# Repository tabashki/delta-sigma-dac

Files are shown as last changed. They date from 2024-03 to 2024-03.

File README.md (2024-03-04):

Delta-Sigma DAC
===============

This repo contains the OrCAD 17.4 schematic and board layout files for a prototype digital-to-analog converter project I created for a *Computer Design of Electronic Circuits* elective course I took at the [Faculty of Physics at Sofia University](https://www.phys.uni-sofia.bg/).

3D visualization of the manufacturing artwork files *(left)* and photo of the first production prototype *(right)*. Manufactured by [JLCPCB](https://jlcpcb.com/).

<p float="left">
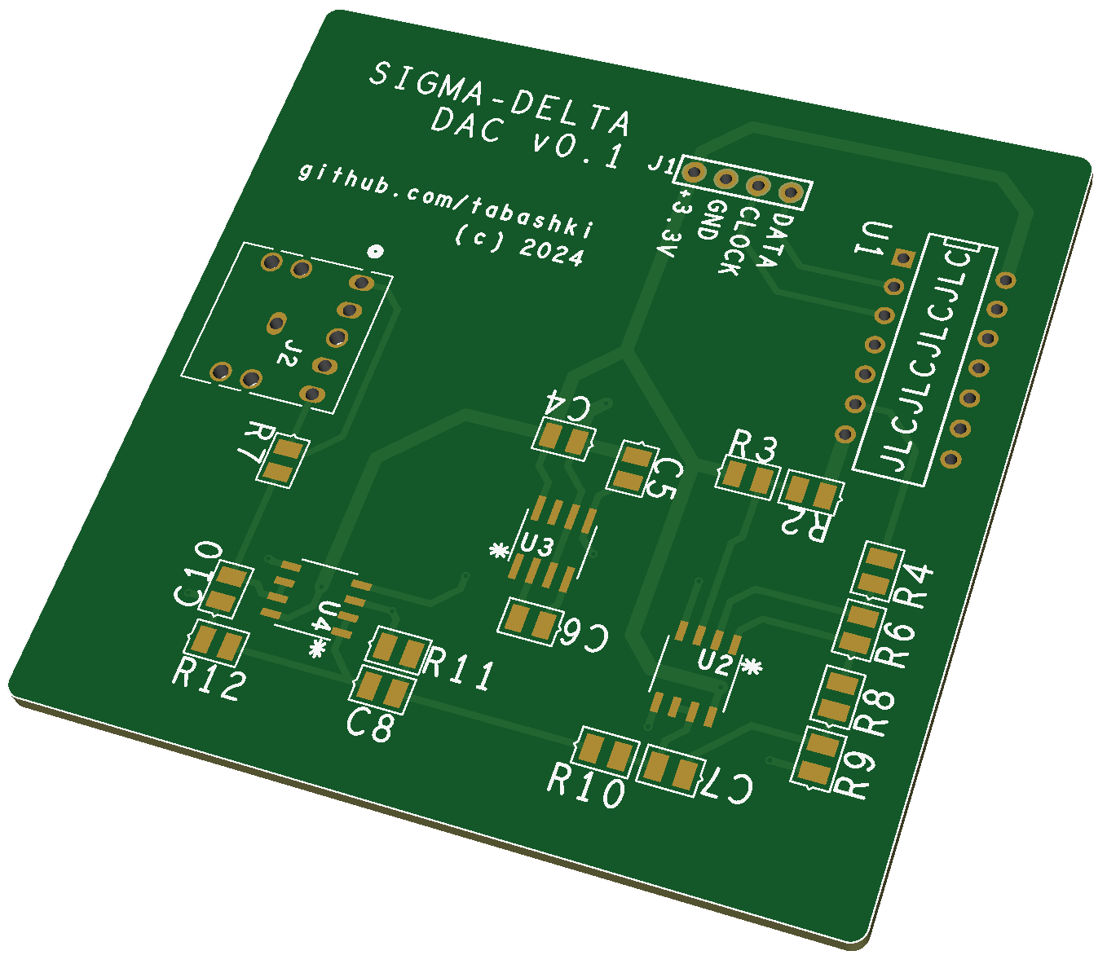
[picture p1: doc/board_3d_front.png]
    
    
</p>

Design Goal
===========

The goal of the project was to construct a rudimentary DAC from discrete digital and analog components that could reasonably function at clocks rates of at least 500 kHz.

The board is powered by a 3.3V DC input and is expected to output a standard -500mV to +500mV line-level signal. The expected input is a 3.3V [pulse-density modulated](https://en.wikipedia.org/wiki/Pulse-density_modulation) digital signal. The signal is latched and demodulated using a 1-bit DAC and a 3-stage, 6th order Butterworth Sallen-Key low-pass filter, the output of which is sent to the 3.5 mm jack output.

Documentation
=============

Signal Path
-----------
The following is a simplified diagram of the signal path:

```mermaid
graph TD;
    in["Clock/Data In"] --> lat["D Latch"];
    lat["D Latch"] --> dac["1-bit DAC (Op-amp)"];
    dac["1-bit DAC (Op-amp)"] --> lpf["Low-Pass Filter Stages 1-3"];
    lpf["Low-Pass Filter Stages 1-3"] --> jack["Jack Output"];
```

Schematic
---------

The full PDF schematic of the cicuit can be found [here](/doc/schematic.pdf).

Bill of Materials
-----------------

An Excel BOM sheet with corresponding links to the Bulgarian parts distrubutor [Comet Electronics](hhttps://www.comet.bg/) can be found [here](/doc/bill_of_materials.xlsx)

Other
-----

A PDF writeup for the coursework in Bulgarian can be found [here](/doc/documentation_bg.pdf).

The PDF slides for the final presentation that was given in front of the class in Bulgarian can be found [here](/doc/presentation_bg.pdf).

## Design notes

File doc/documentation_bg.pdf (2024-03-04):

## Софийски Университет „Св. Климент Охридски“

### Физически Факултет

# П Р О Е К Т

## на тема

## Изработване на прототипна платка за ΔΣ цифрово-

## аналогов преобразувател (ЦАП)

## курс

## Компютърно Проектиране на Електронни Схеми

Изготвил: | Иван Руменов Табашки
Ф. №: | 6PH0900015
Проверил: | доц. д-р Станимир Колев

## Съдържание

## 1. Увод и цел

Делта-сигма модулаторите са схеми за преобразуване на аналогови сигнали в

редица високочестотни цифрови импулси. С допълнителна цифрова филтрация може

този изходен сигнал да се превърне в еквивалентен дискретизиран по време и квантуван

по амплитуда сигнал. Както при други видове аналогово-цифрови преобразуватели,

важно е да имаме нискочестотен пред-филтър след аналоговия вход за да се избегнат

ефектите от aliasing. Но за разлика от другите ЦАП схеми, при делта-сигма

модулаторите се налага в порядък по-висока честота на дискретизация от максималната

на входния сигнал [1]. По този начин може да реконструираме сигнала до bit-depth или

sampling-rate, какъвто желаем като се използва още по-висока тактова честота.

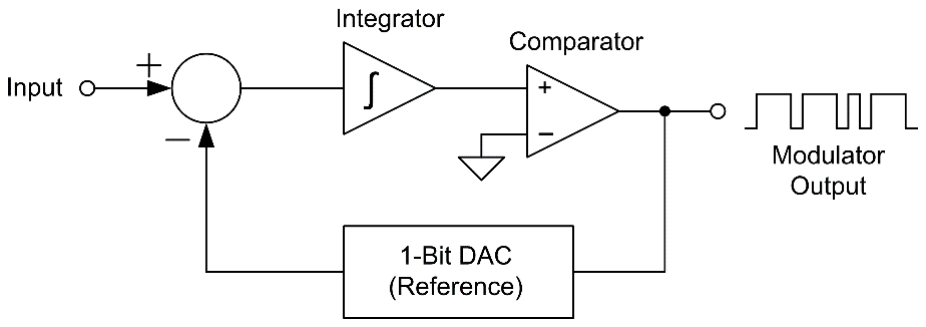
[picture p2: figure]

Фигура 1. Блок-схема на прост делта-сигма модулатор [2]

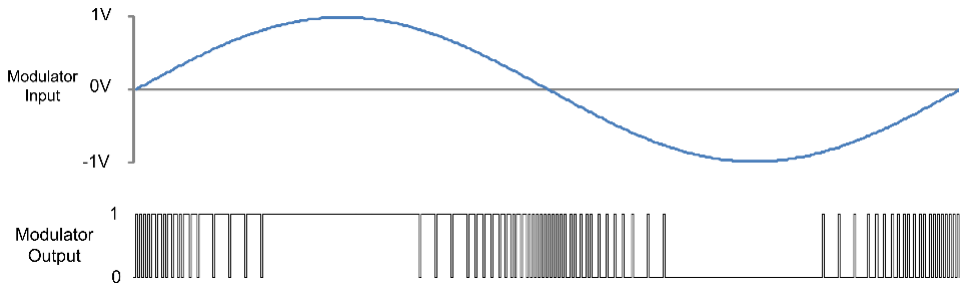
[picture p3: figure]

Фигура 2. Примерен изходен сигнал на модулатора [2]

Делта-сигма демодулаторите съответно извършват обратната операция, на

изхода им се получава нискочестотен аналогов сигнал на базата на високочестотния

цифров pulse-density модулиран сигнал на техния вход. Това позволява те да вършат

работа на цифрово-аналогови преобразуватели, като може да се наложи цифрова

обработка на сигнала, ако той е квантуван с висок bit-depth.

В този проект ще се разглежда създаването точно на такъв делта-сигма ЦАП,

който да служи за генериране на стандартен, line level звуков сигнал [3], така че да може

с усилвател той да бъде възпроизведен на високоговорител.

## 2. Описание на схемата

Схемата се състои от 4 основни блока - генератор на отрицателно -3.3V отправно

напрежение, входен D-тригер, който управлява еднобитов ЦАП, осъществен чрез

операционен усилвател, изхода на който минава през активен Sallen-Key Butterworth

нискочестотен филтър. Схемата е предвидена да бъде захранвана с постоянно 3.3V

напрежение от външен източник. Отрицателното -3.3V напрежение се генерира с

помощта на charge-pump DC-to-DC интегрална схема TC7660.

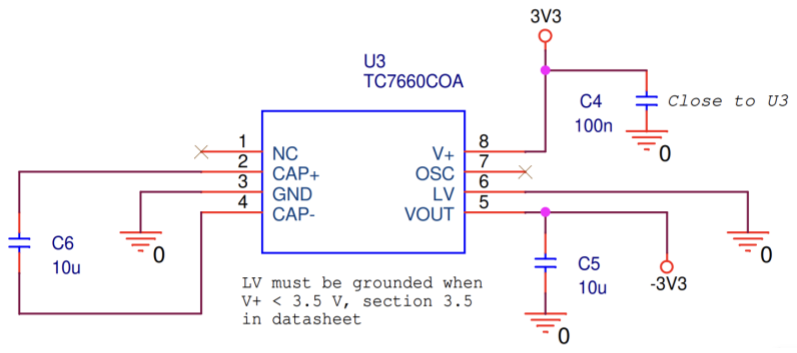
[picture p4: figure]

Фигура 3. Схемата на генератора на -3.3V, конфигурацията е взета от TC7660 datasheet

D-тригера е интегрална схема SN74HC74N, на която D и CLK входовете са външни

за цялата схема и са изведени на входния конектор, и се очаква да се управляват от външен микроконтролер Raspberry Pi Pico [4], а Q̅ изхода е свързан към отрицателния

вход на операционен усилвател с +3.3V и -3.3V захранване. Отрицателната обратна

връзка на операционния усилвател е подбрана, така че коефициента му на усилване да е

приблизително 0.303, а чрез резисторен делител се добавя постоянно положително

отместване приблизително 0.5V. Целта на това е да превърне цифровия изход със CMOS

нива (0 ÷ 3.3V) към -0.5V ÷ 0.5V нивата очаквани за стандартен line-level изход [3].

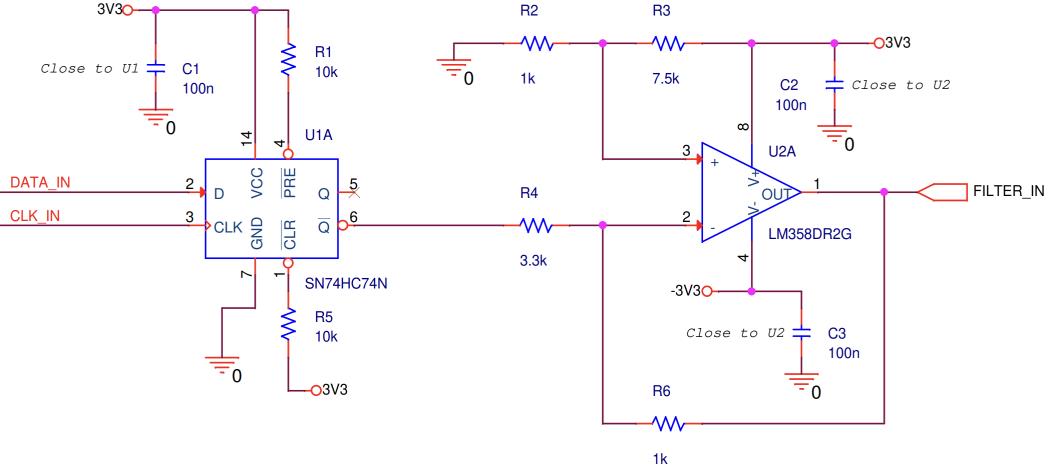
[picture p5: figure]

Фигура 4. Схемата преди нискочестотния филтър

След професионална консултация, в схемата са добавени 100 nF кондензатори на

захранванията на всяка интегрална схема, това е с цел да се избегнат смущения по

захранващите релси и земи. В схемата тези кондензатори са отбелязани с допълнителни

отметки “Close to Ux” за да е ясно по време на дизайн на платката, че те трябва да са във

физическа близост до дадената интегрална схема.

Най-сложната част от цялата схема е финалния нискочестотен филтър, на който

параметрите съществено влияят върху качествата на цялата схема като ЦАП. За целта е

избран да е Butterworth филтър, поради добрата му линейност и липса на сериозни

изкривявания на сигнала близо до cutoff честотата.

Интегралната схема LM358 съдържа двойка операционни усилватели, така че като

за начало имаме един свободен операционен усилвател, който може да използваме за

изграждането на филтър тип Sallen-Key. Проблема, е че така най-много да можем

Butterworth филтър от втори ред да конструираме. По тази причина с добавката на още

една интегрална схема LM358, ще имаме общо 3 операционни усилвателя на

разположение, с които може да създаден Butterworth филтър от 6-ти ред, който има доста

по-добра стръмност след cutoff честотата му.

Тъй като сметките за стойностите на филтър с толкова стъпала вече не е тривиално,

за целта се използва онлайн калкулатора на Uwe Beis [5], който може да сметне филтър

до 10-ти ред, както и да наглася стойностите на компонентите да са от стандартните

поредици. За малко подсигуряване поради вариации в компонентите, филтъра е

пресметнат да е с cutoff честота 16 kHz, резултатните стойности са записани във фиг. 5.

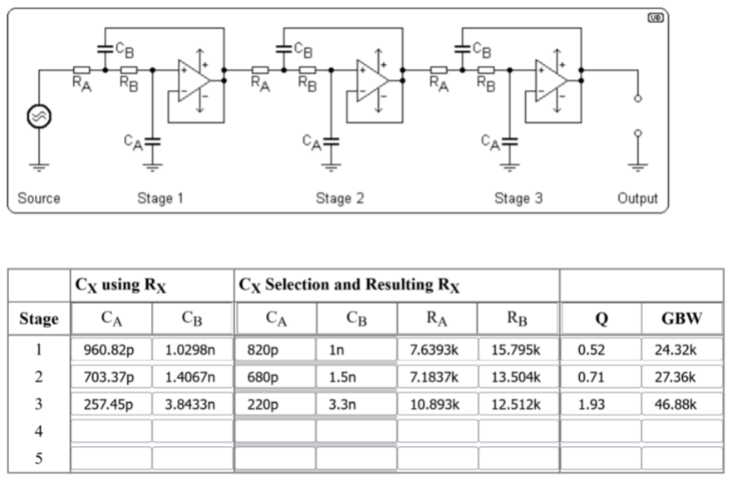
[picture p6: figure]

Фигура 5. Резултата от калкулатора [5]

## 3. PSpice симулации на схемата

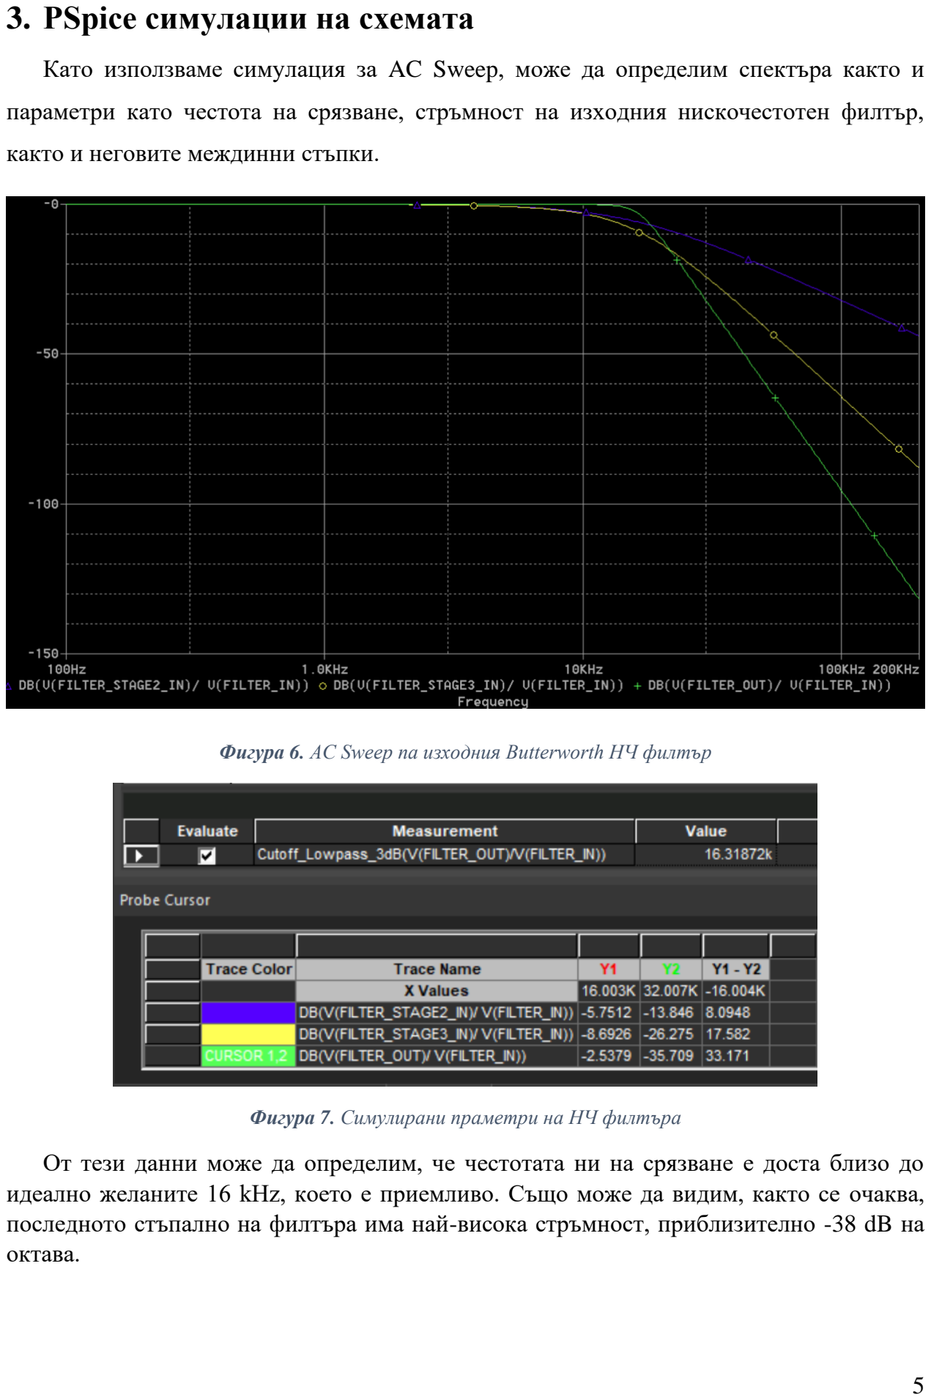
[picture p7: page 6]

Като използваме симулация за AC Sweep, може да определим спектъра както и

параметри като честота на срязване, стръмност на изходния нискочестотен филтър,

както и неговите междинни стъпки.

Фигура 6. AC Sweep nа изходния Butterworth НЧ филтър

Фигура 7. Симулирани праметри на НЧ филтъра

От тези данни може да определим, че честотата ни на срязване е доста близо до идеално желаните 16 kHz, което е приемливо. Също може да видим, както се очаква, последното стъпално на филтъра има най-висока стръмност, приблизително -38 dB на октава.

## 4. Дизайн и производство на печатната платка

За производство на прототипните платки е избрана популярната Хонконгска

фирма за производство на прототипни печатни платки JLCPCB [6]. Причините са

ниската цена и високото качество за прототипни печатни платки за размери под 100 x

100mm, и личен опит с производителя. В случая схемата е достатъчно проста да се

вмести в по-малки ограничения и за удобство е избран размер на платката 2500 x 2500

mil (приблизително 63.5 x 63.5 mm) при създаването на новия Board проект в OrCAD.

С цел минимизиране на възможностите за смущение между високочестотния вход

и аналоговата филтрация на изхода, на платката -3.3V захранването и операционните

усилватели са разположени на другия край на печатната платка от входа и D-тригера.

Като повечето фирми извършващи подобна дейност, нужните им входни данни са

под формата на стандартни Gerber файлове, описващи всеки слой на печатната платка.

Като в случая е важно да се спазва точно наименованието изискано от фирмата, за да

може правилно да се прехвърли дизайна към производствената апаратура.

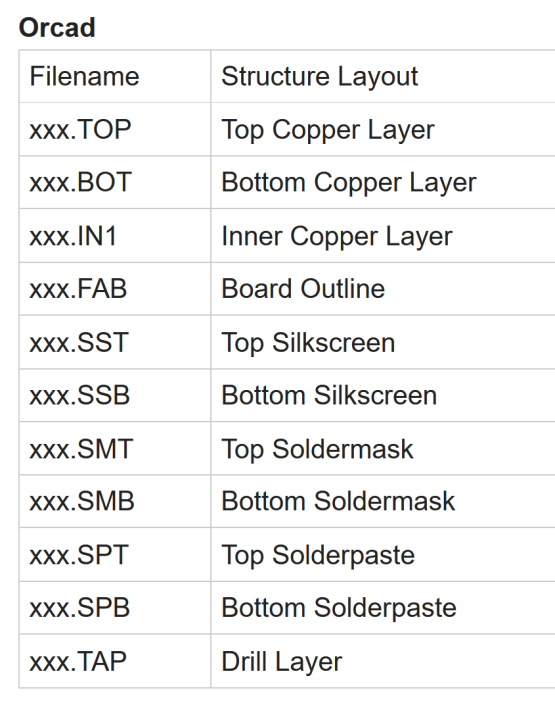
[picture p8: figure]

Фигура 8. Файловата структура изискана от JLCPCB [7]

Важно е да се отбележи, че в OrCAD drill файловете се генерират отделно от

artwork (gerber) файловете и обикновено имат различно наименование от останалите файлове. В случая на този проект е създаден един допълнителен jlcpcb_archive.bat

скриптов файл в pcb папката, който се грижи за обработка на имената на файловете и

генерирането на финалния .zip архив, който е изпратен за производство.

Тъй като фирмата произвежда платки от много клиенти едновременно на големи

панели, с цел да може да проследяват кои платки към кои поръчки принадлежат,

обикновено се налага допълнителна маркировка на платките. Обикновено позицията на

тази маркировка върху белия печат на платката се определя едностранно от

производителя, което може да не е желано. По тази причина може клиента изрично да

посочи позицията на номера на поръчката, като постави текста “JLCJLCJLCJLC” на

белия печат, в случая този текст е поставен под интегралната схема на D-тригера, тъй

като точно пасва на площадката му, и текста ще бъде закрит от компонента след като

бъде монтиран.

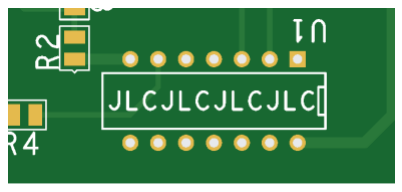
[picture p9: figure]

Фигура 9. Изрично определяне на позицията на номера на поръчката при UI

В сайта на JLCPCB има допълнително инструмент, чрез който може да се

визуализират както и двумерно, така и тримерно слоевете на подадените файлове от

клиента, за проверка на тяхното съответствие към очакваните.

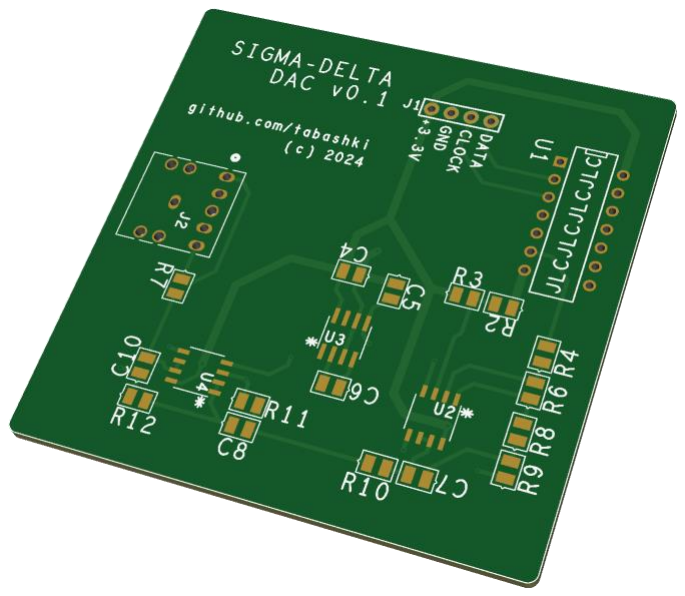
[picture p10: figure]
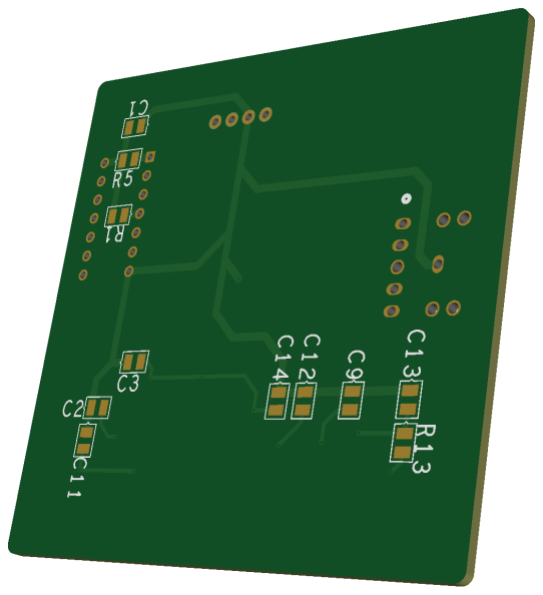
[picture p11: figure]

Фигура 10. Тримерни изображения на финалните производствени Gerber файлове

от двете страни на платката

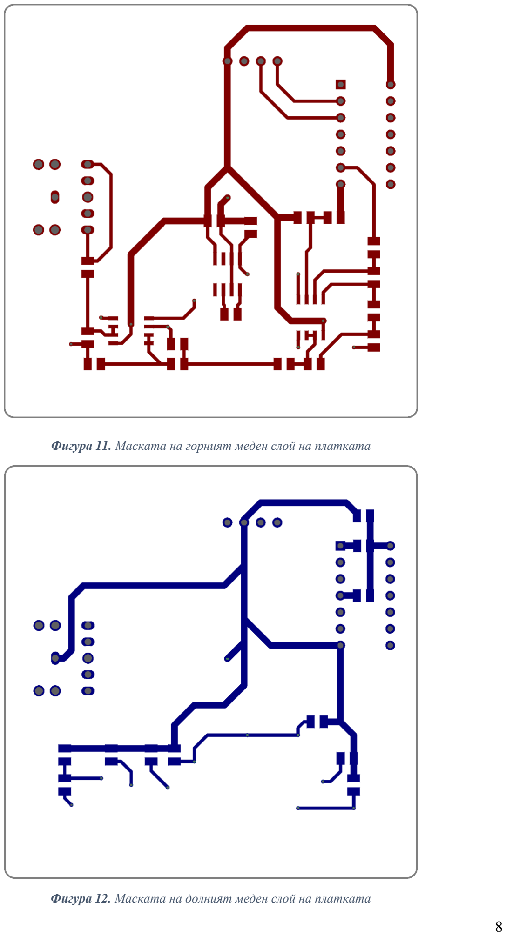
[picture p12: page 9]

Фигура 11. Маската на горният меден слой на платката

Фигура 12. Маската на долният меден слой на платката

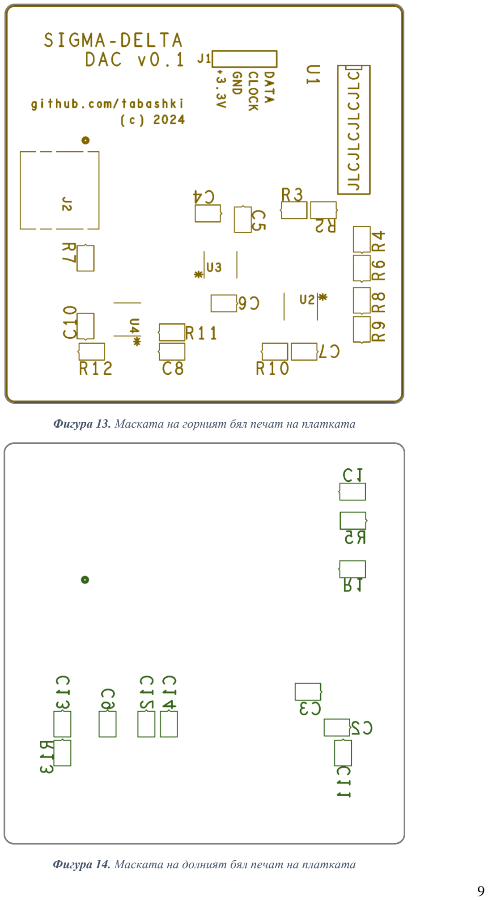
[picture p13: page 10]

Фигура 13. Маската на горният бял печат на платката

Фигура 14. Маската на долният бял печат на платката

## 5. Библиография

[1] Wikipedia, „Delta-sigma modulation,“ [Онлайн]. Available:

https://en.wikipedia.org/wiki/Delta-sigma_modulation.

[2] Texas Instruments, „Delta-sigma ADC basics: Understanding the delta-sigma

modulator,“ [Онлайн]. Available:

https://e2e.ti.com/blogs_/archives/b/precisionhub/posts/delta-sigma-adc-basics-

understanding-the-delta-sigma-modulator.

[3] Wikipedia, „Line level,“ [Онлайн]. Available:

https://en.wikipedia.org/wiki/Line_level.

[4] Raspberry Pi, „Raspberry Pi Pico and Pico W Documentation,“ [Онлайн]. Available:

https://www.raspberrypi.com/documentation/microcontrollers/raspberry-pi-

pico.html.

[5] U. Beis, „Active Low-Pass Filter Design and Dimensioning,“ [Онлайн]. Available:

https://www.beis.de/Elektronik/Filter/ActiveLPFilter.html.

[6] JLCPCB, „JLCPCB,“ [Онлайн]. Available: https://jlcpcb.com/.
[7] JLCPCB, „How to generate Gerber files in different software,“ [Онлайн]. Available:

https://jlcpcb.com/help/article/4-how-to-generate-gerber-files-in-different-software.

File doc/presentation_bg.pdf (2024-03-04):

# ИЗРАБОТВАНЕ НА ПРОТОТИПНА ПЛАТКА ЗА ΔΣ ЦАП

Презентирал: | Иван Табашки
Факултетен №: | 6PH0900015
Курс: | 3 – КИ

## Увод

- В днешния време огромна част от звукозаписа, който слушаме е от цифрови носители или източници
- За да се постигне висок bit-depth с по-малка схема от R-2R мрежите, много модерни ЦАП използват ΔΣ модулация

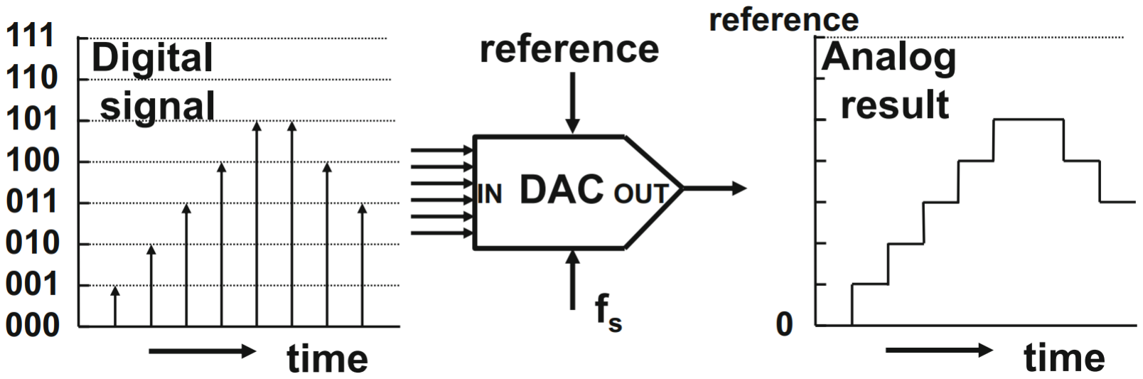
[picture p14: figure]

## Делта-сигма модулация

- ΔΣ модулаторите са АЦП схеми, които превръщат аналогов сигнал в поредица високочестотни цифрови импулси (pulse-density modulation)

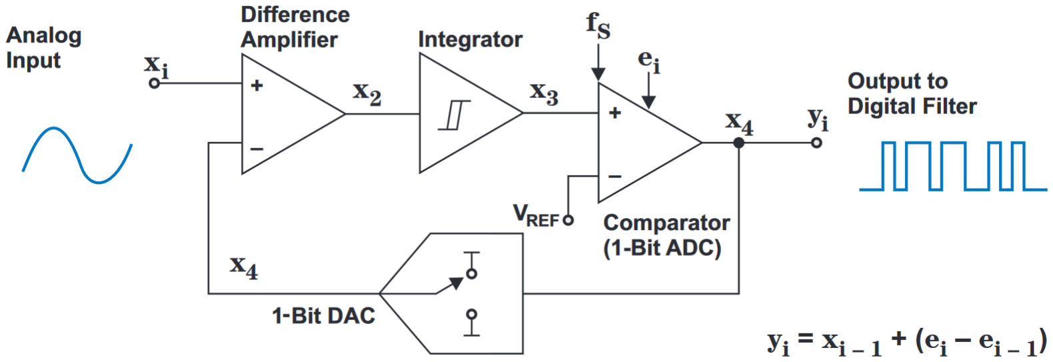
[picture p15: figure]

## Делта-сигма демодулация

- Може да демодулираме генерирания цифров сигнал и да изработим ЦАП с произволен bit-depth
- Налага се висока тактова честота (oversampling) и качествен изходен нискочестотен филтър

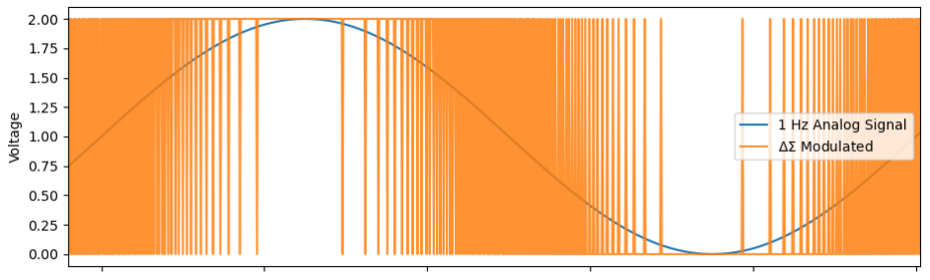
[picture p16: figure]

## Схема (стр. 1 от 2)

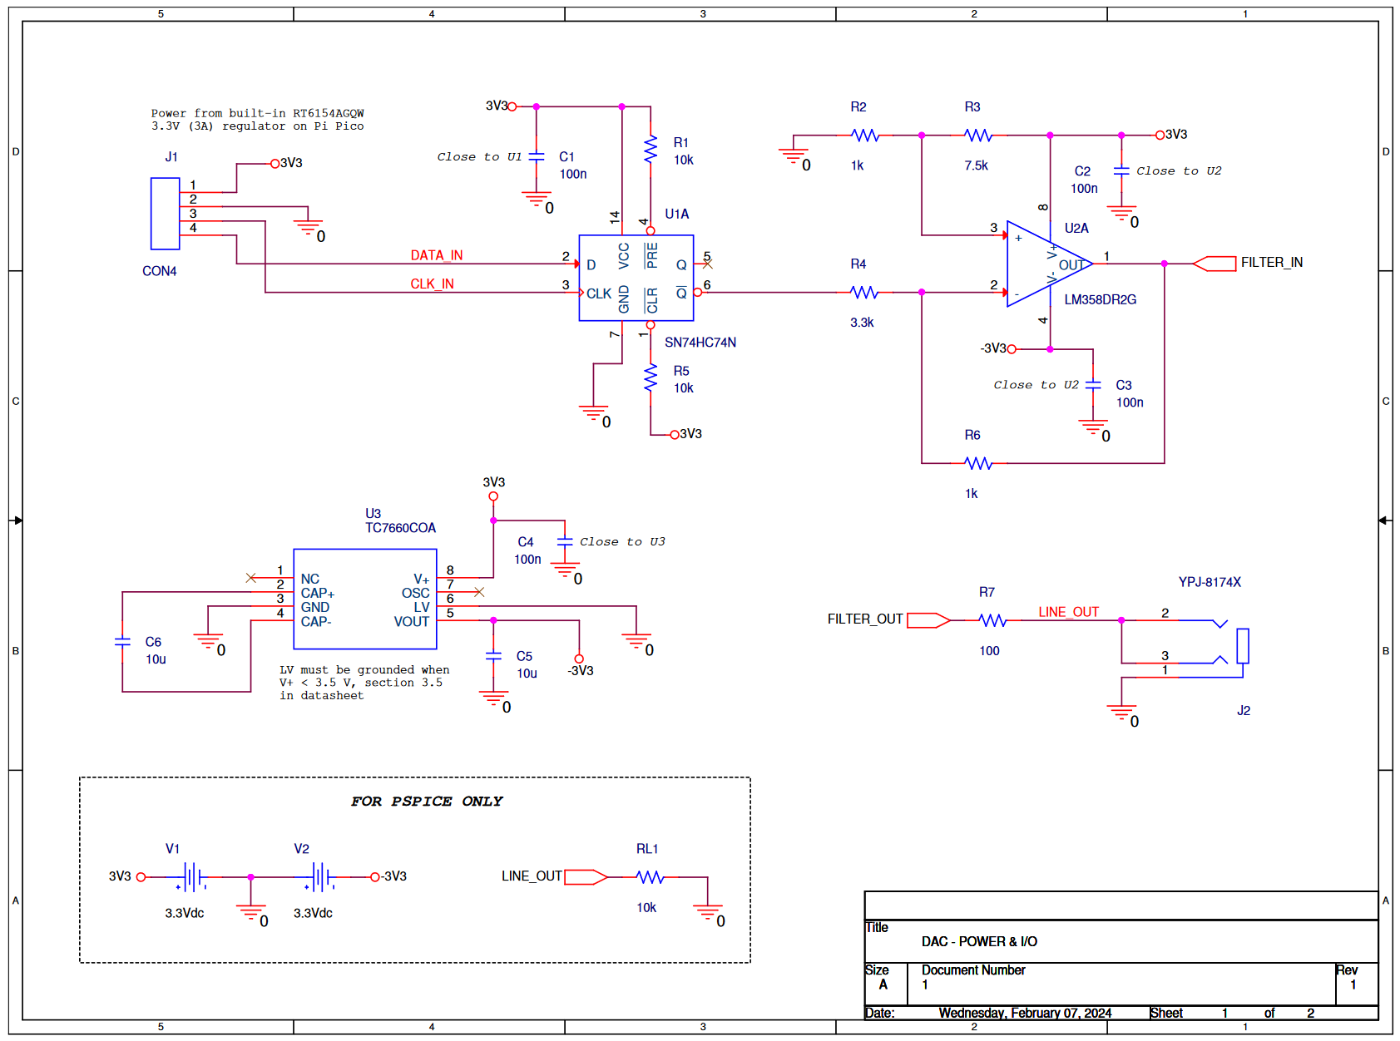
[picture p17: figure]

## Схема (стр. 1 от 2)

- Цифрови входове и захранване

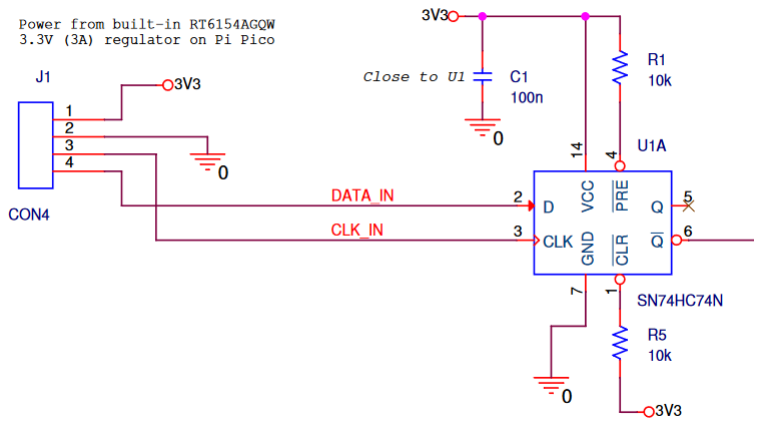
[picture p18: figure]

## Схема (стр. 1 от 2)

- Генератор на отрицателно -3.3V напрежение

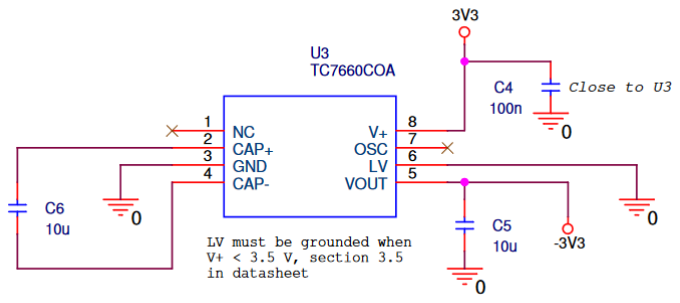
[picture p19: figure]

## Схема (стр. 1 от 2)

- 1-битов ЦАП с Line Level изход -0.5V до +0.5V

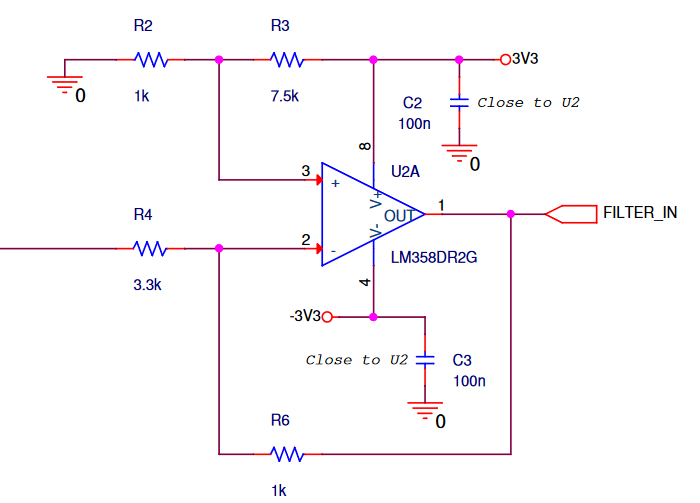
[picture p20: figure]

## Схема (стр. 1 от 2)

- Изход към 3.5 мм аудио жака

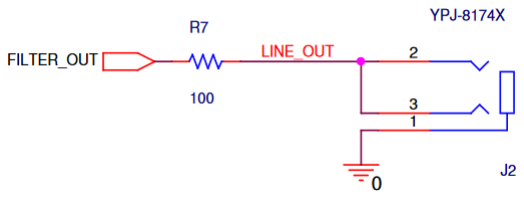
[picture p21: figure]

## Схема (стр. 2 от 2)

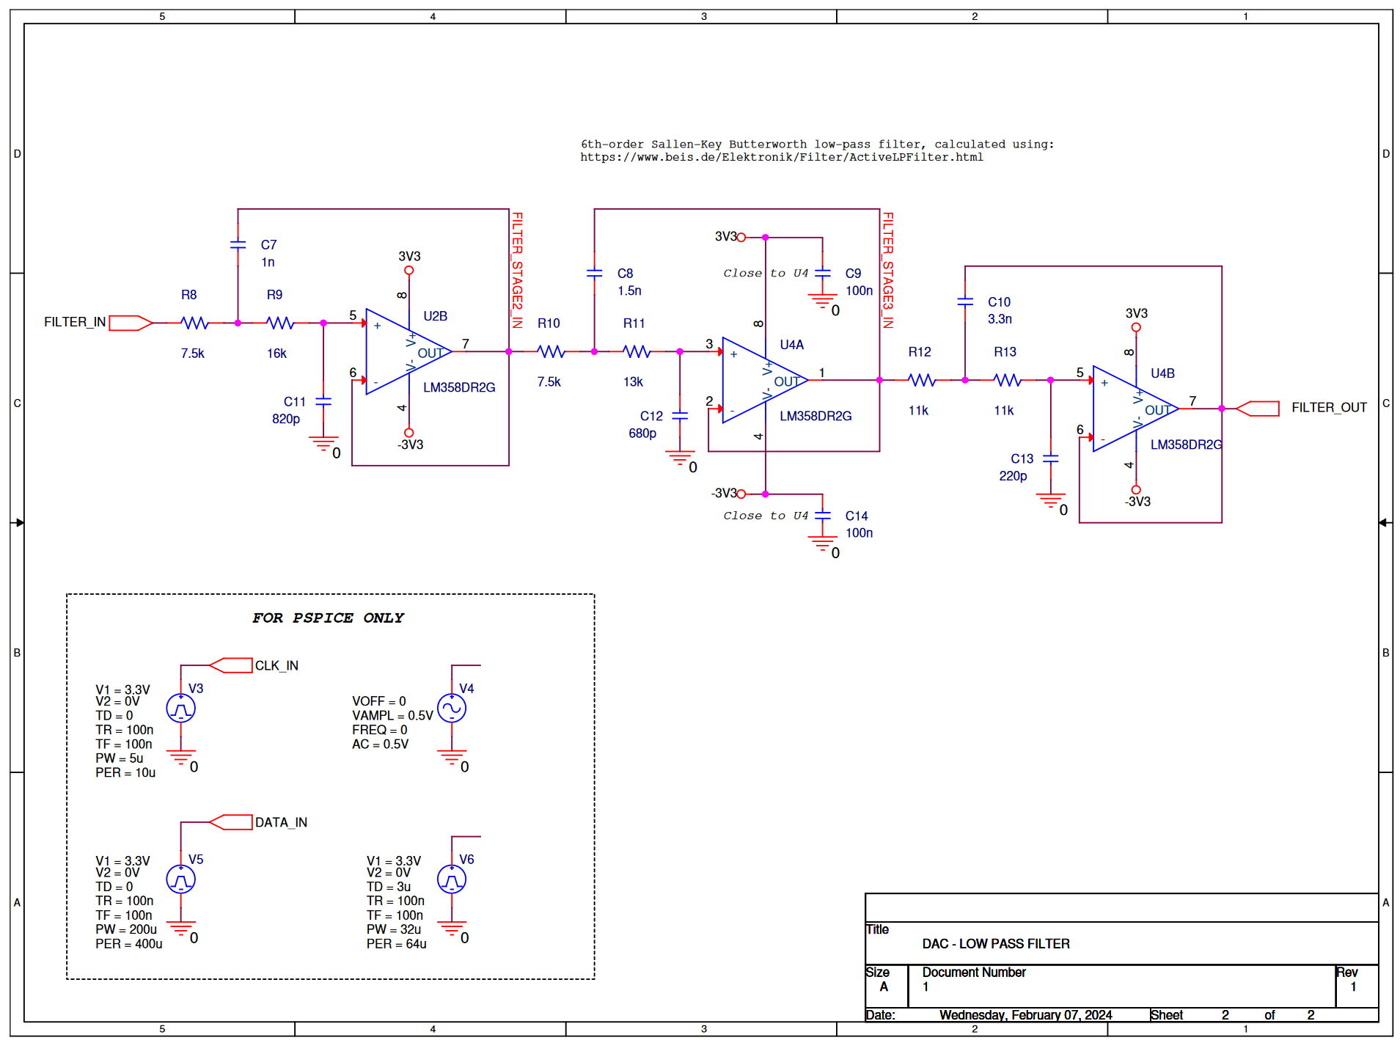
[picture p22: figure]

## Схема (стр. 2 от 2)

- Sallen-Key Butterworth филтър, 6-ти ред

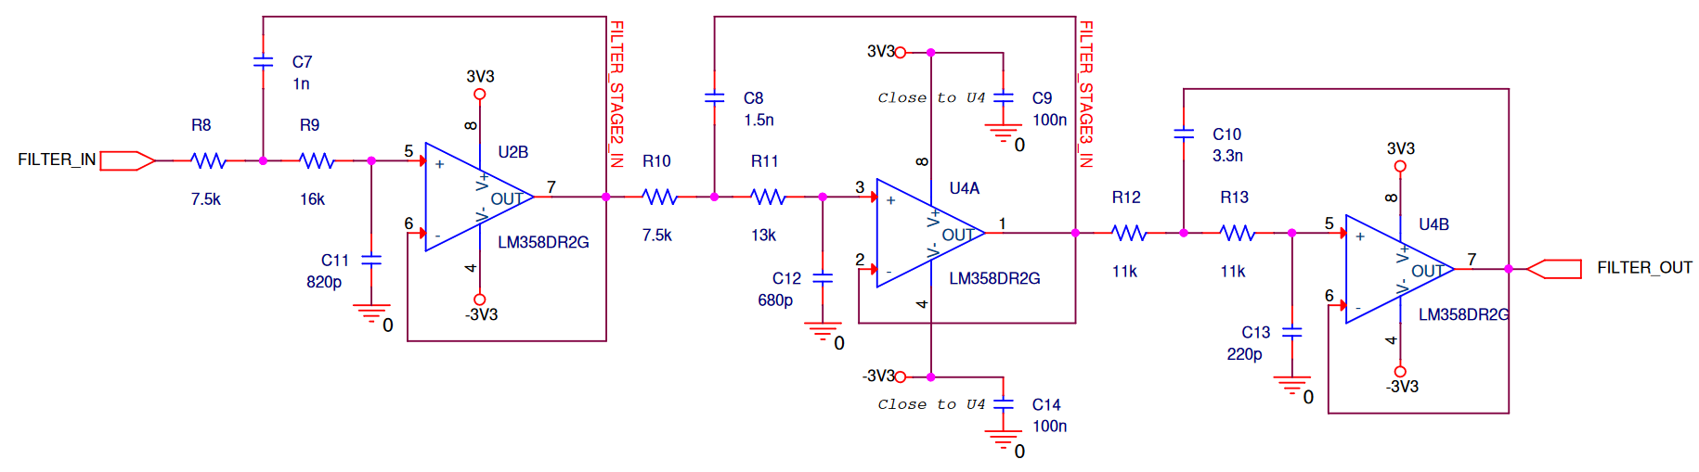
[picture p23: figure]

## Схема (стр. 2 от 2)

- Сметнат с онлайн калкулатора на Uwe Beis[6]

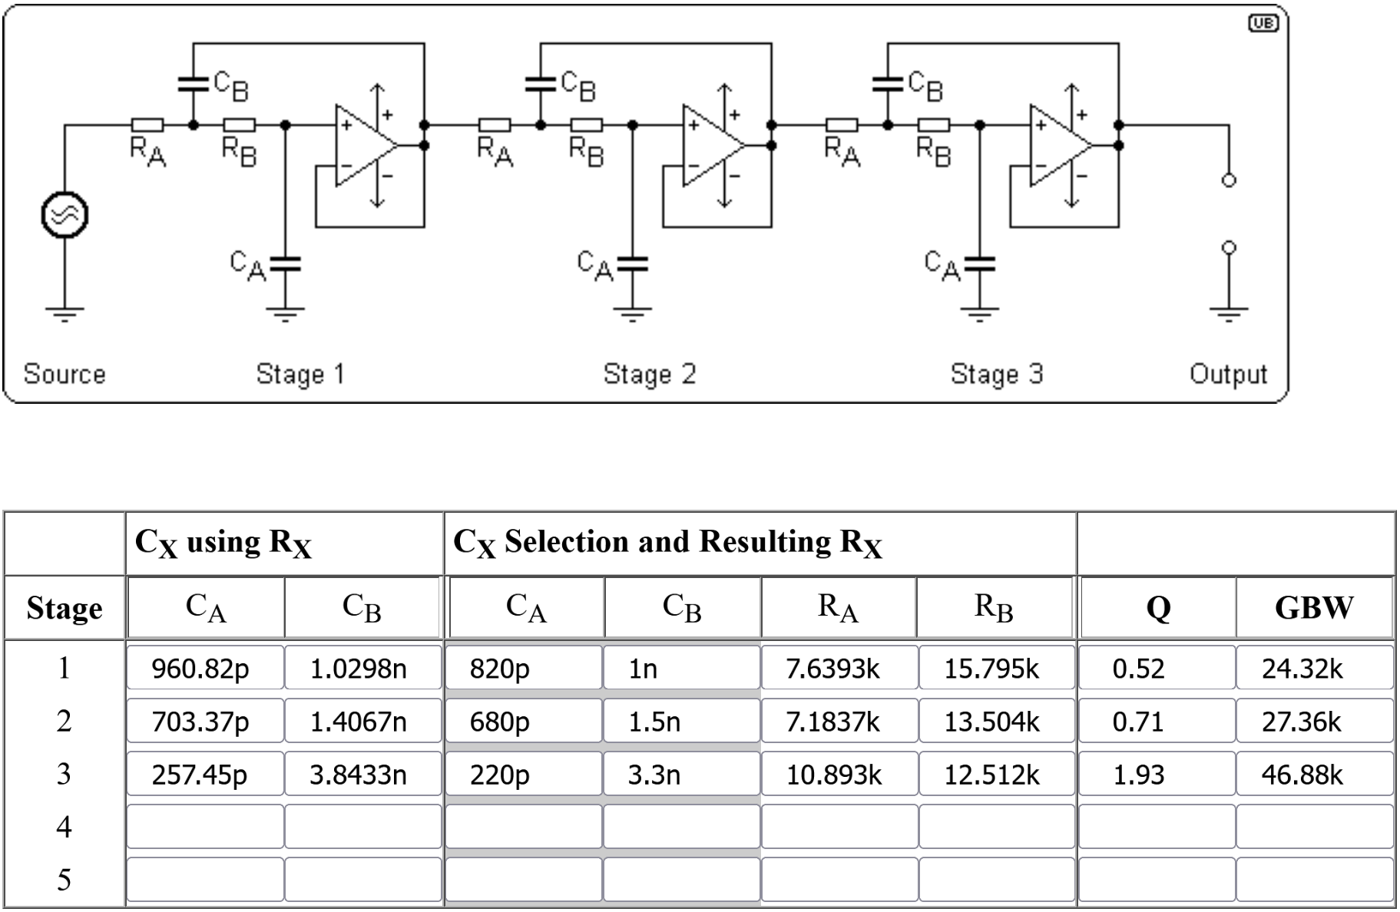
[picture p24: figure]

## PSpice симулация на филтъра

- AC sweep да потвърдим параметрите на НЧ филтъра

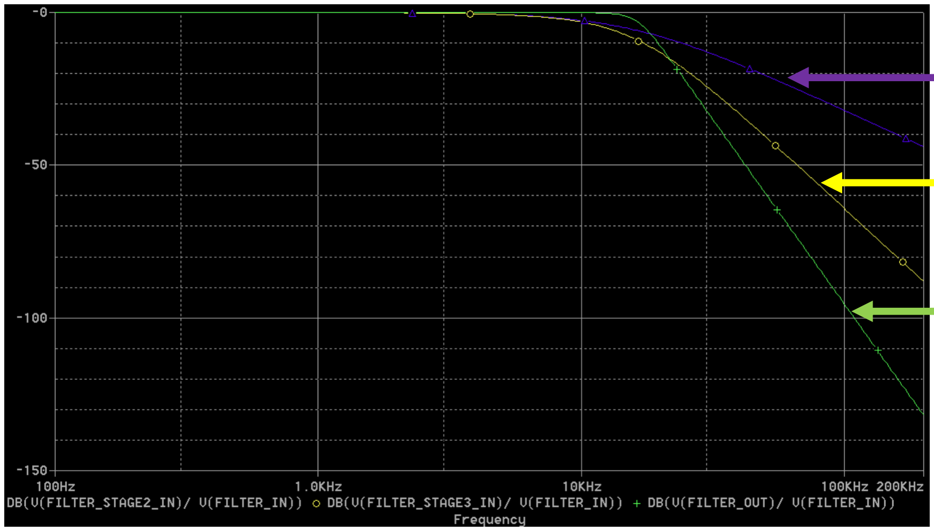
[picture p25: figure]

1-во стъпало

2-ро стъпало

Изходно
стъпало

## PSpice симулация на филтъра

- 16.3 kHz честота на срязване, | -33.2 | dB/octave


## PSpice симулация на филтъра

- Monte-Carlo симулация (±10% за C, ±1% за R)


## Изработка на печатната платка


## Изработка на печатната платка


## Изработка на печатната платка


## Изработка на печатната платка


## Изработка на печатната платка


## Финален монтаж?


# БЛАГОДАРЯ ЗА ВНИМАНИЕТО!

## Източници

1. Understanding Data Converters, Texas Instruments, 1995
2. Analog-to-Digital Conversion, Marcel J.M. Pelgrom, Springer Nature, 2022
3. https://www.ti.com/lit/an/slyt423a/slyt423a.pdf
4. https://www.allaboutcircuits.com/textbook/digital/chpt-13/tracking-adc/
5. https://www.allaboutcircuits.com/textbook/digital/chpt-13/slope-integrating-adc/
6. https://www.beis.de/Elektronik/Filter/ActiveLPFilter.html
7. https://jlcpcb.com/help/article/4-how-to-generate-gerber-files-in-different-software

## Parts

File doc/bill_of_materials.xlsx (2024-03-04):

Bill Of Materials | Page1
Item | Quantity | Reference | Part | Footprint | Comet.bg Link
1 | 6 | C1,C2,C3,C4,C9,C14 | 100n | smd080512 | https://store.comet.bg/Catalogue/Product/16789/
2 | 2 | C5,C6 | 10u | smd080512 | https://store.comet.bg/Catalogue/Product/9549/
3 | 1 | C7 | 1n | smd080512 | https://store.comet.bg/Catalogue/Product/16937/
4 | 1 | C8 | 1.5n | smd080512 | https://store.comet.bg/Catalogue/Product/23220/
5 | 1 | C10 | 3.3n | smd080512 | https://store.comet.bg/Catalogue/Product/4530/
6 | 1 | C11 | 820p | smd080512 | https://store.comet.bg/Catalogue/Product/23203/
7 | 1 | C12 | 680p | smd080512 | https://store.comet.bg/Catalogue/Product/4529/
8 | 1 | C13 | 220p | smd080512 | https://store.comet.bg/Catalogue/Product/23152/
9 | 1 | J1 | CON4 | JUMPER4 | https://store.comet.bg/Catalogue/Product/5220358/
10 | 1 | J2 | YPJ-8174X | SJ1-3523N_CUD | https://store.comet.bg/Catalogue/Product/3970/
11 | 2 | R1,R5 | 10k | smd080512 | https://store.comet.bg/Catalogue/Product/37675/
12 | 2 | R2,R6 | 1k | smd080512 | https://store.comet.bg/Catalogue/Product/37650/
13 | 3 | R3,R8,R10 | 7.5k | smd080512 | https://store.comet.bg/Catalogue/Product/3545/
14 | 1 | R4 | 3.3k | smd080512 | https://store.comet.bg/Catalogue/Product/24903/
15 | 1 | R7 | 100 | smd080512 | https://store.comet.bg/Catalogue/Product/37623/
16 | 1 | R9 | 16k | smd080512 | https://store.comet.bg/Catalogue/Product/3551/
17 | 1 | R11 | 13k | smd080512 | https://store.comet.bg/Catalogue/Product/3549/
18 | 2 | R12,R13 | 11k | smd080512 | https://store.comet.bg/Catalogue/Product/3548/
19 | 1 | U1 | SN74HC74N | DIP10014W300L800 | https://store.comet.bg/Catalogue/Product/18093/
20 | 2 | U2,U4 | LM358DR2G | SOIC-8_ONS | https://store.comet.bg/Catalogue/Product/20560/
21 | 1 | U3 | TC7660COA | SOIC8-N_MC_MCH | https://store.comet.bg/Catalogue/Product/29475/

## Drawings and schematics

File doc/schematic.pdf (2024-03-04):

3 - 2

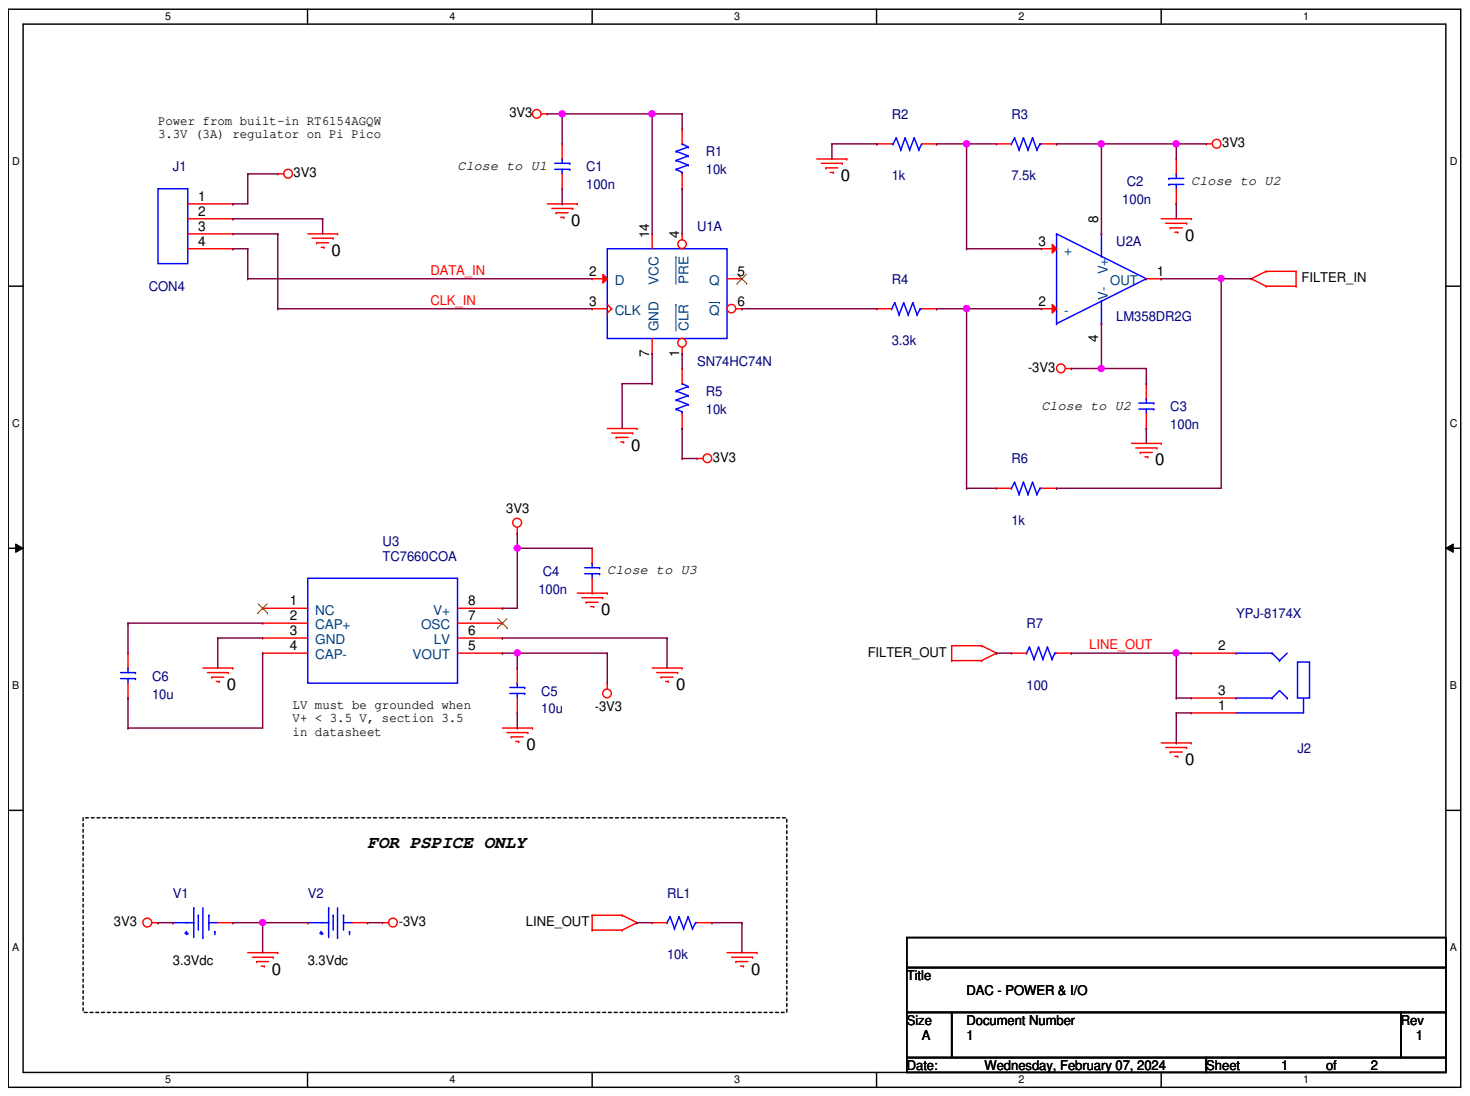
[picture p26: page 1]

Power from built-in RT6154AGQW
3.3V (3A) regulator on Pi Pico

LV must be grounded when
V+ < 3.5 V, section 3.5
in datasheet

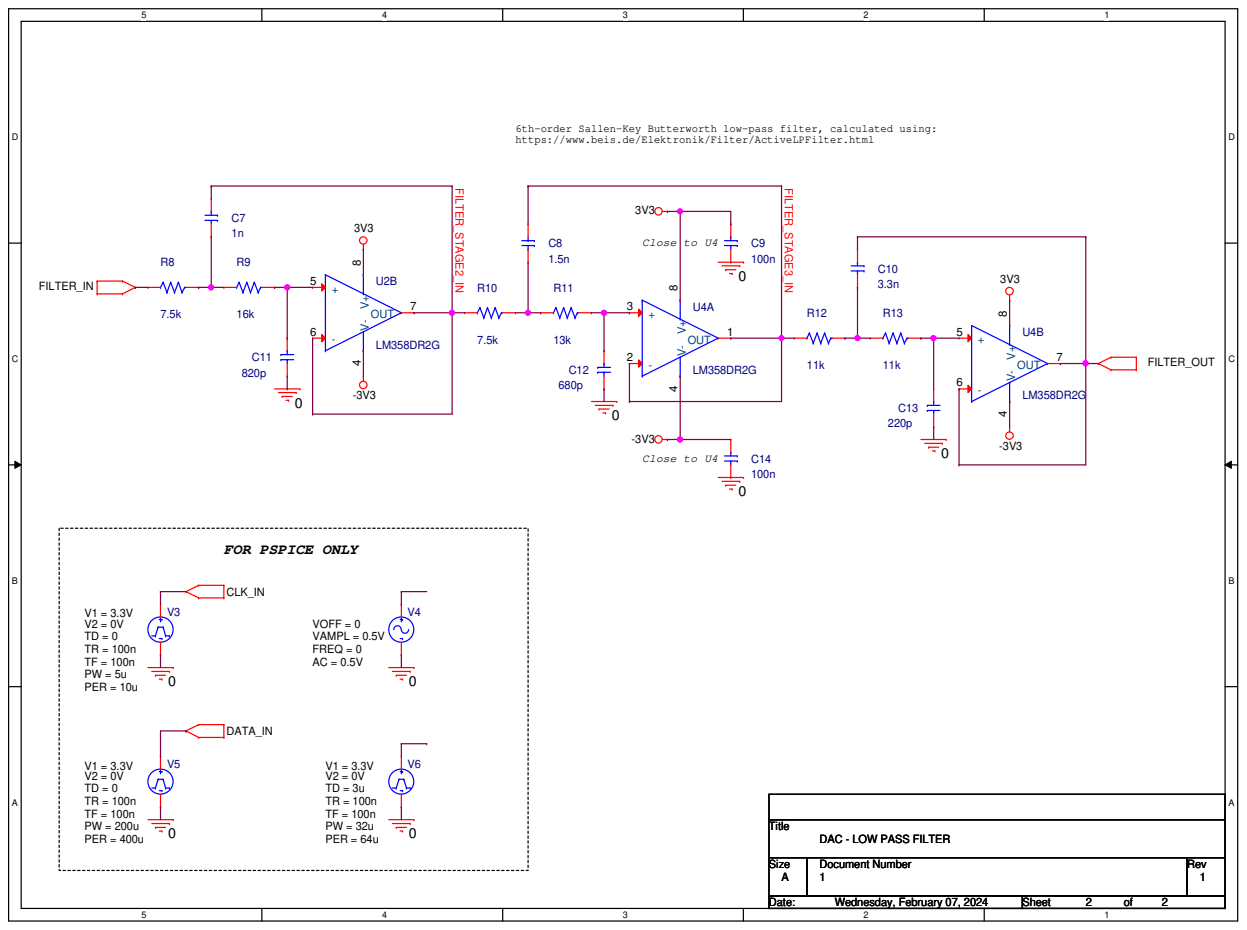
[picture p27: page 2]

6th-order Sallen-Key Butterworth low-pass filter, calculated using:
https://www.beis.de/Elektronik/Filter/ActiveLPFilter.html

DAC - LOW PASS FILTER
